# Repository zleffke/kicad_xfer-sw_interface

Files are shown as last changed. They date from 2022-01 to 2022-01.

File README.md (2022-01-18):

# kicad_xfer-sw_interface
Pulse Latching RF Transfer Switch Interface for VTGS SX-Band System.  
V1, Rev- Designed to Control a Single [Relcomm RTS-TS3AB-I](https://rfrelaystore.com/product/rts-ts3ab-i/) Transfer Switch.  

The VTGS SX-Band System uses four RTS-TS3AB-I transfer switches to set the RF receive path to an X310 USRP with Dual UBX-160s.
Two transfer switches select the receive band for the USRP Band A RX2 port and Band B RX2 port (S or X).
Two transfer switches select the receive polarization for the selected band (RHCP or LHCP).

## [Relcomm RTS-TS3AB-I](https://rfrelaystore.com/product/rts-ts3ab-i/) Transfer Switch Description
See linked product for full datasheet and feature list.  Features listed below are the pertinent features for the control circuit.
- Pulse Latching, short duration pulse on coil sets latched position.
- 28V Coil Voltage, common negative, pulse on positive side of Coil 1 or 2.
- Indicator feedback, 1P2T switch indicates position.

## V1, Rev- Circuit Design Features
This version / revision submitted to osh park for PCB fab on 20220118.
- TTL Level Control from MCU (+5V / +3V3)
- TTL Level Feedback for MCU (+5V / +3V3)
- Optically Isolated Control (ILD207T)
- LED Current Position Indicator (POS1 - RED, POS2 - BLUE)
- LED Set Position Indicator (pulsed, both green)
- Relay Coil Control via dual W6PQL based FET Switch circuits

## Credit where its due:
The transfer switches in this design are controlled by a [High Current DC Switch](https://www.w6pql.com/high_current_solid-state_dc_switch.htm) based on the W6PQL design.  The specific P-Channel MOSFET is modified for smaller form factor and lower current draw.  The DISABLE feature is not needed and not implemented.

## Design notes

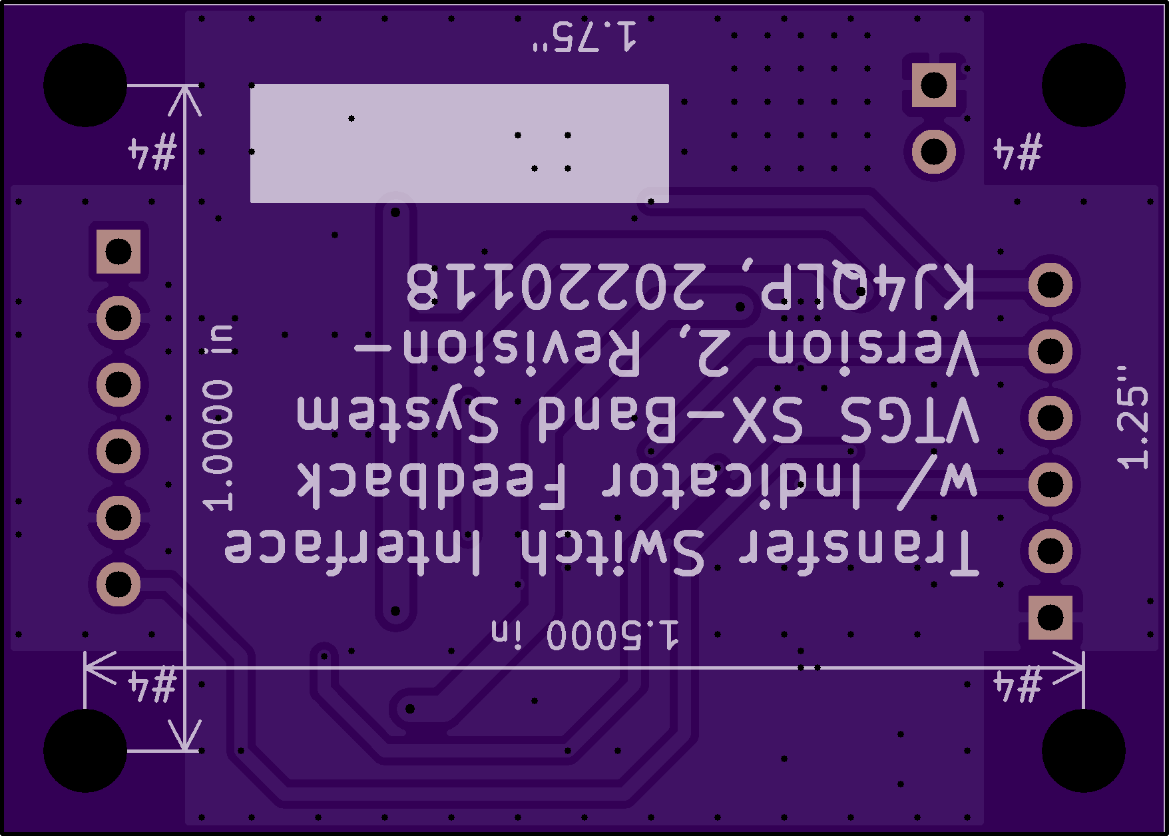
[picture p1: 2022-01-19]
v2/rev-/osh_park_bottom_view.png

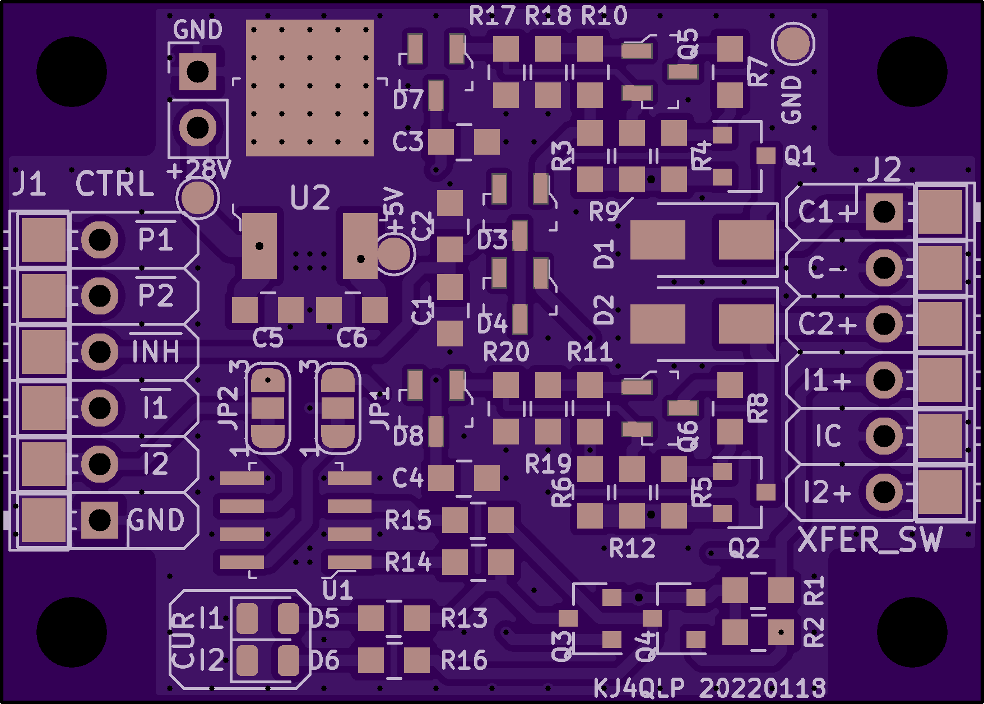
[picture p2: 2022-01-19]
v2/rev-/osh_park_top_view.png

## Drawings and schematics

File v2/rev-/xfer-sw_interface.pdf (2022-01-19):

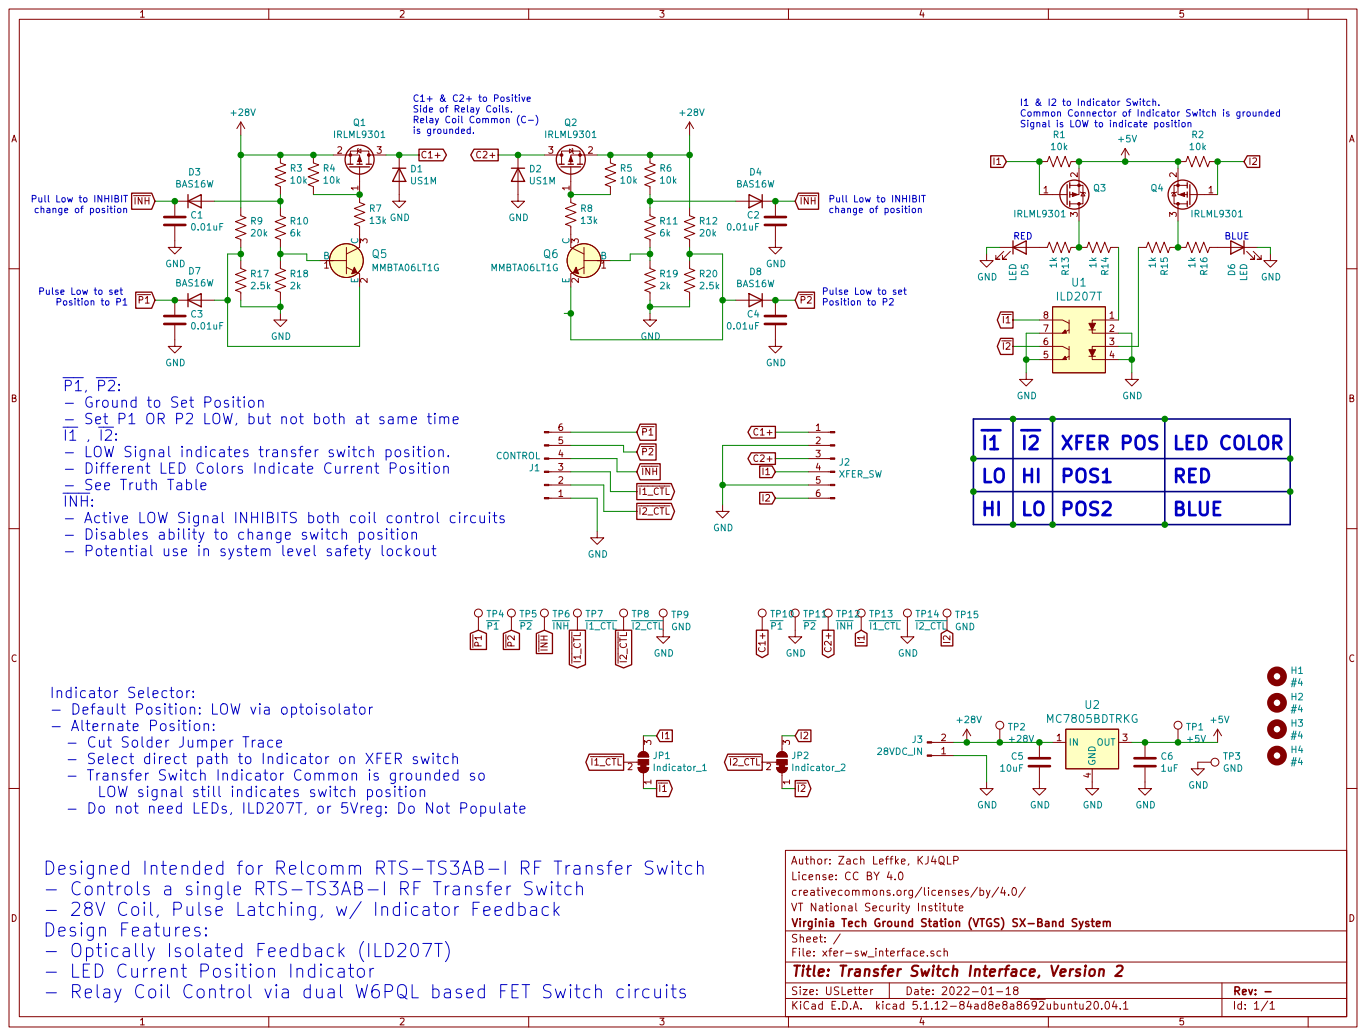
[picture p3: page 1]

Signal is LOW to indicate position C1+ & C2+ to Positive Side of Relay Coils.
10kTP9 GND

I1 & I2 to Indicator Switch. Common Connector of Indicator Switch is grounded

change of position Pulse Low to set Position to P2 Pull Low to INHIBIT
change of position Pulse Low to set Position to P1

Pull Low to INHIBIT
INH

- Ground to Set Position
- Set P1 OR P2 LOW, but not both at same time
- LOW Signal indicates transfer switch position.
- Different LED Colors Indicate Current Position
- See Truth Table
INH:
- Active LOW Signal INHIBITS both coil control circuits
- Disables ability to change switch position
- Potential use in system level safety lockout

Indicator Selector:
- Default Position: LOW via optoisolator
- Alternate Position:
- Cut Solder Jumper Trace
- Select direct path to Indicator on XFER switch
- Transfer Switch Indicator Common is grounded so
LOW signal still indicates switch position
- Do not need LEDs, ILD207T, or 5Vreg: Do Not Populate

creativecommons.org/licenses/by/4.0/ License: CC BY 4.0 Author: Zach Leffke, KJ4QLP

- Controls a single RTS-TS3AB-I RF Transfer Switch
- 28V Coil, Pulse Latching, w/ Indicator Feedback
Design Features:
- Optically Isolated Feedback (ILD207T)
- LED Current Position Indicator
- Relay Coil Control via dual W6PQL based FET Switch circuits

VT National Security Institute
File: xfer-sw_interface.sch Sheet: / Virginia Tech Ground Station (VTGS) SX-Band System

Id: 1/1 Title: Transfer Switch Interface, Version 2

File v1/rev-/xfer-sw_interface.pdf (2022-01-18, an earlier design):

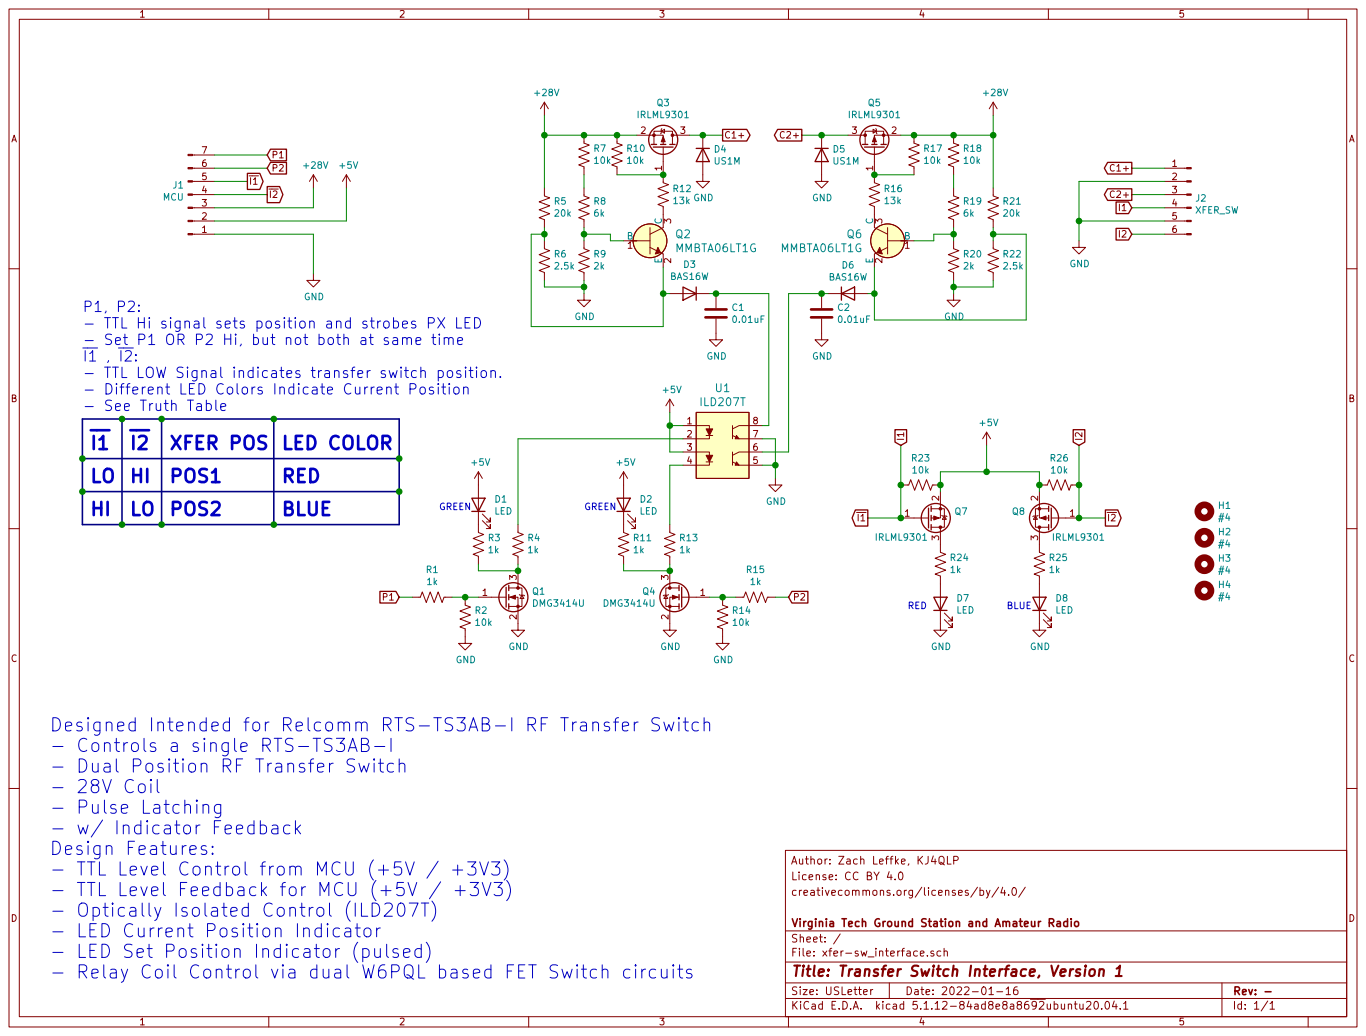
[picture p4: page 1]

- TTL Hi signal sets position and strobes PX LED
- Set P1 OR P2 Hi, but not both at same time
- TTL LOW Signal indicates transfer switch position.
- Different LED Colors Indicate Current Position
- See Truth Table

RED GREEN LED COLOR
RED
BLUE

Designed Intended for Relcomm RTS-TS3AB-I RF Transfer Switch
- Controls a single RTS-TS3AB-I
- Dual Position RF Transfer Switch
- 28V Coil
- Pulse Latching
- w/ Indicator Feedback
Design Features:
- TTL Level Control from MCU (+5V / +3V3)
- TTL Level Feedback for MCU (+5V / +3V3)
- Optically Isolated Control (ILD207T)
- LED Current Position Indicator
- LED Set Position Indicator (pulsed)
- Relay Coil Control via dual W6PQL based FET Switch circuits

creativecommons.org/licenses/by/4.0/ License: CC BY 4.0 Author: Zach Leffke, KJ4QLP

File: xfer-sw_interface.sch Sheet: / Virginia Tech Ground Station and Amateur Radio

Id: 1/1 Title: Transfer Switch Interface, Version 1

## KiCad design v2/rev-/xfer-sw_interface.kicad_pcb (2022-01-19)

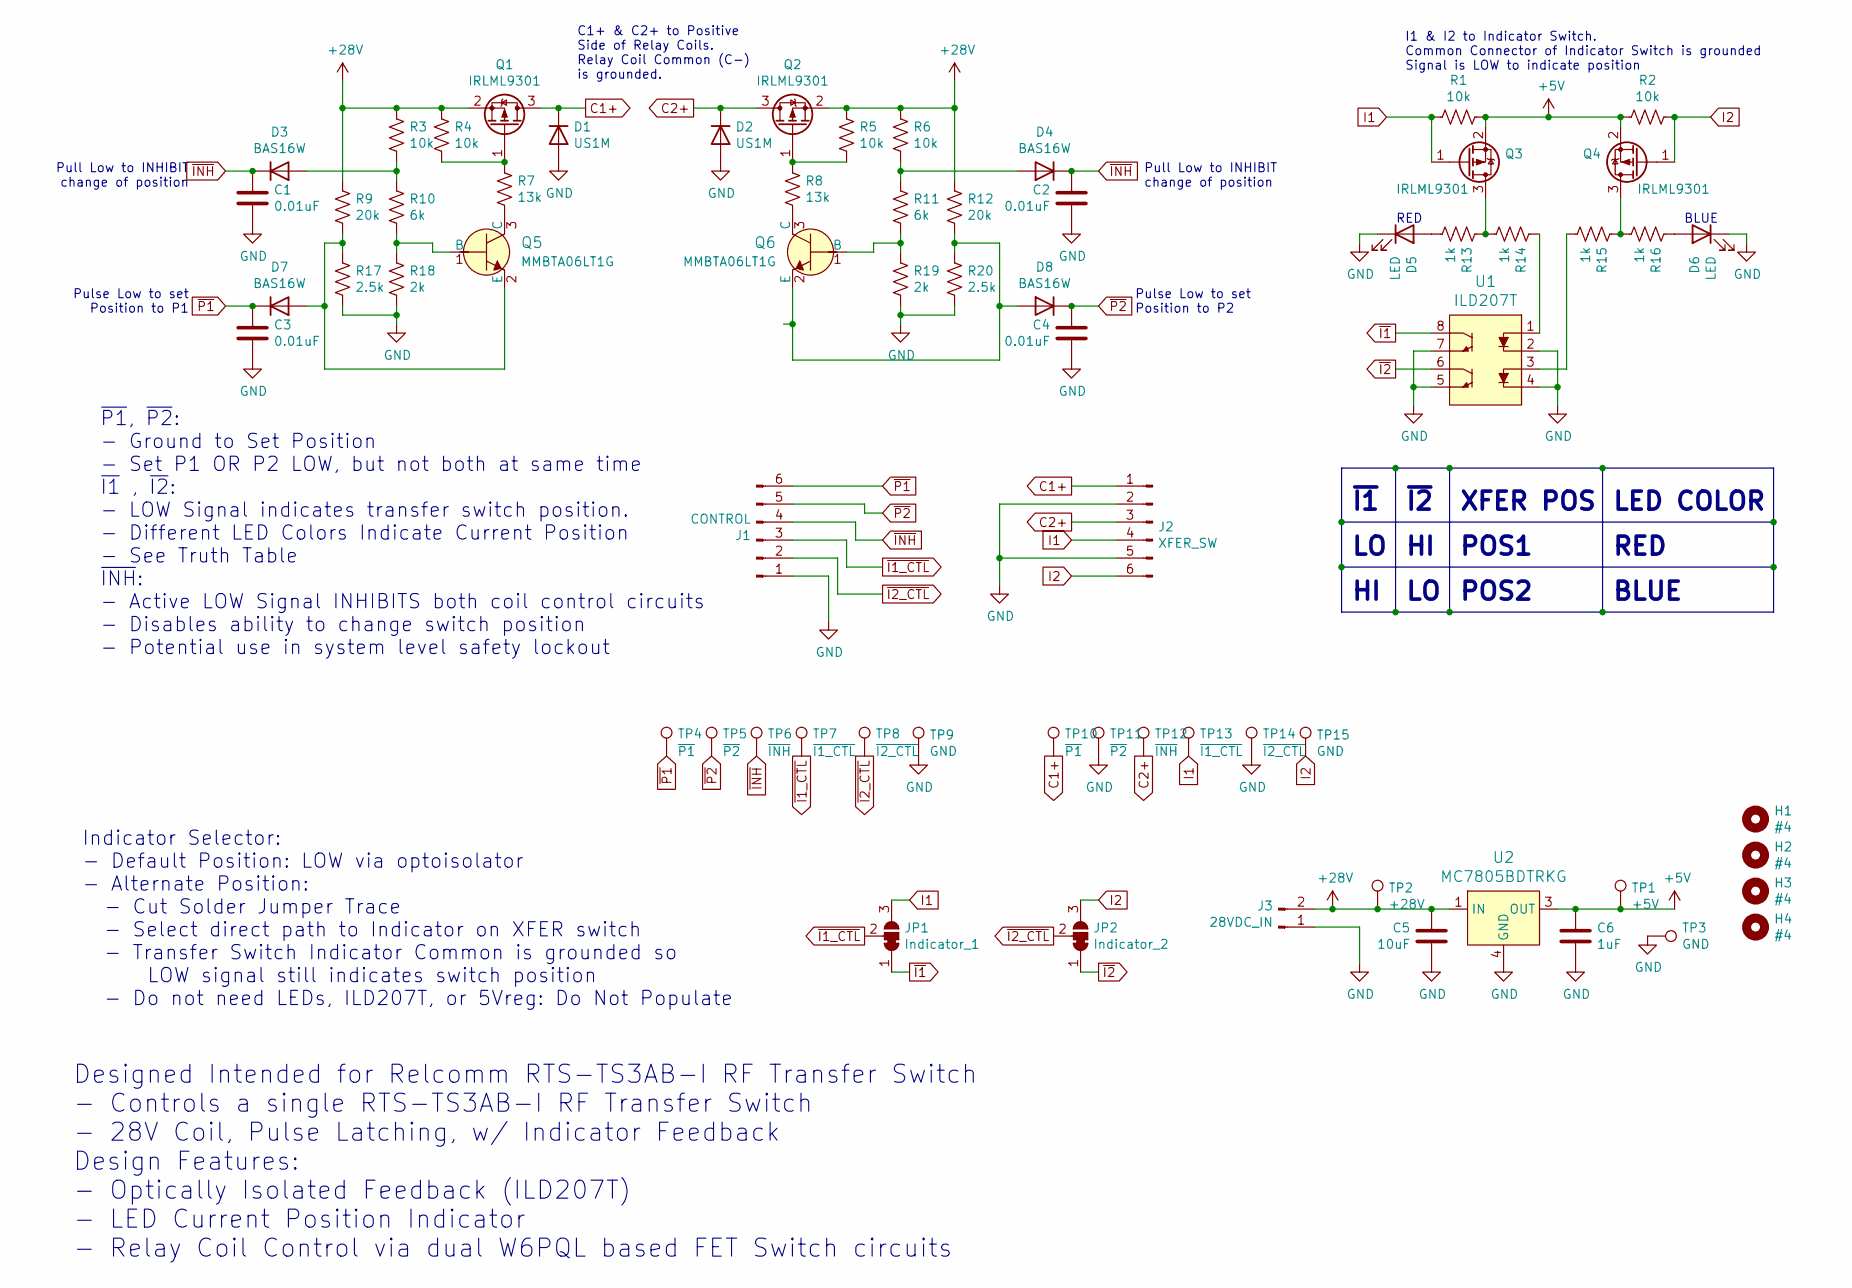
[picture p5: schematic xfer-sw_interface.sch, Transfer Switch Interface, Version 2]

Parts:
C1, C2, C3, C4: 0.01uF; 0805
C5: 10uF; 0805
C6: 1uF; 0805
D1, D2: US1M; D_SMA
D3, D4, D7, D8: BAS16W; SOT-23-3
D5, D6: LED; LED_0805_2012Metric
H1, H2, H3, H4: #4; MountingHole_3.2mm_M3
J1: CONTROL; PinHeader_1x06_P2.54mm_Horizontal
J2: XFER_SW; PinHeader_1x06_P2.54mm_Horizontal
J3: 28VDC_IN; PinHeader_1x02_P2.54mm_Vertical
JP1: Indicator_1; SolderJumper-3_P1.3mm_Bridged12_RoundedPad1.0x1.5mm_NumberL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
JP2: Indicator_2; SolderJumper-3_P1.3mm_Bridged12_RoundedPad1.0x1.5mm_NumberL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
Q1, Q2, Q3, Q4: IRLML9301; SOT-23
Q5, Q6: MMBTA06LT1G; SOT-23-3; MPN MMBTA06LT1G; Digi-Key_PN MMBTA06LT1GOSCT-ND
R1, R2, R3, R4, R5, R6: 10k; 0805
R7, R8: 13k; 0805
R9, R12: 20k; 0805
R10, R11: 6k; 0805
R13, R14, R15, R16: 1k; 0805
R17, R20: 2.5k; 0805
R18, R19: 2k; 0805
TP1: +5V; TestPoint_Pad_D1.5mm
TP2: +28V; TestPoint_Pad_D1.5mm
TP3: GND; TestPoint_Pad_D1.5mm
TP4, TP10: ~P1; TestPoint_Pad_2.0x2.0mm
TP5, TP11: ~P2; TestPoint_Pad_2.0x2.0mm
TP6, TP12: ~INH; TestPoint_Pad_2.0x2.0mm
TP7, TP13: ~I1_CTL; TestPoint_Pad_2.0x2.0mm
TP8, TP14: ~I2_CTL; TestPoint_Pad_2.0x2.0mm
TP9, TP15: GND; TestPoint_Pad_2.0x2.0mm
U1: ILD207T; SOIC-8_W3.9mm; MPN ILD207T; Digi-Key_PN 751-1310-1-ND
U2: MC7805BDTRKG; TO-252-3; MPN MC7805BDTRKG; Digi-Key_PN MC7805BDTRKGOSCT-ND

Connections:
+5V: C6.1, Q3.2 (S), Q4.2 (S), R1.1, R2.2, TP1.1, U2.3 (OUT)
+28V: C5.1, J3.2, Q1.2 (S), Q2.2 (S), R3.2, R4.2, R5.2, R6.2, R9.2, R12.2, TP2.1, U2.1 (IN)
C1+: D1.1 (K), J2.1, Q1.3 (D), TP10.1
C2+: D2.1 (K), J2.3, Q2.3 (D), TP12.1
GND: C1.2, C2.2, C3.2, C4.2, C5.2, C6.2, D1.2 (A), D2.2 (A), D5.1 (K), D6.1 (K), J1.1, J2.2, J2.5, J3.1, R17.1, R18.1, R19.1, R20.1, TP3.1, TP9.1, TP11.1, TP14.1, U1.2, U1.4, U1.5, U1.7, U2.4 (GND)
I1: J2.4, JP1.3 (B), Q3.1 (G), R1.2, TP13.1
I2: J2.6, JP2.3 (B), Q4.1 (G), R2.1, TP15.1
unnamed: D3.1 (A), R3.1, R10.2
unnamed: D4.1 (A), R6.1, R11.2
unnamed: D5.2 (A), R13.1
unnamed: D6.2 (A), R16.2
unnamed: D7.1 (A), Q5.2 (E), R9.1, R17.2
unnamed: D8.1 (A), Q6.2 (E), R12.1, R20.2
unnamed: Q1.1 (G), R4.1, R7.1
unnamed: Q2.1 (G), R5.1, R8.1
unnamed: Q3.3 (D), R13.2, R14.1
unnamed: Q4.3 (D), R15.2, R16.1
unnamed: Q5.1 (B), R10.1, R18.2
unnamed: Q5.3 (C), R7.2
unnamed: Q6.1 (B), R11.1, R19.2
unnamed: Q6.3 (C), R8.2
unnamed: R14.2, U1.1
unnamed: R15.1, U1.3
~I1: JP1.1 (A), U1.8
~I1_CTL: J1.3, JP1.2 (C), TP7.1
~I2: JP2.1 (A), U1.6
~I2_CTL: J1.2, JP2.2 (C), TP8.1
~INH: C1.1, C2.1, D3.3 (K), D4.3 (K), J1.4, TP6.1
~P1: C3.1, D7.3 (K), J1.6, TP4.1
~P2: C4.1, D8.3 (K), J1.5, TP5.1

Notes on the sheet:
~P1~, ~P2~: - Ground to Set Position - Set P1 OR P2 LOW, but not both at same time ~I1~ , ~I2~: - LOW Signal indicates transfer switch position. - Different LED Colors Indicate Current Position - See Truth Table ~INH~: - Active LOW Signal INHIBITS both coil control circuits - Disables ability to ch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
~I1
~I2
XFER POS
POS2
POS1
RED
BLUE
LED COLOR
Designed Intended for Relcomm RTS-TS3AB-I RF Transfer Switch - Controls a single RTS-TS3AB-I RF Transfer Switch - 28V Coil, Pulse Latching, w/ Indicator Feedback Design Features: - Optically Isolated Feedback (ILD207T) - LED Current Position Indicator - Relay Coil Control via dual W6PQL based FET S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
Indicator Selector: - Default Position: LOW via optoisolator - Alternate Position: - Cut Solder Jumper Trace - Select direct path to Indicator on XFER switch - Transfer Switch Indicator Common is grounded so LOW signal still indicates switch position - Do not need LEDs, ILD207T, or 5Vreg: Do Not Po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
C1+ & C2+ to Positive Side of Relay Coils. Relay Coil Common (C-) is grounded.
I1 & I2 to Indicator Switch. Common Connector of Indicator Switch is grounded Signal is LOW to indicate position
Pulse Low to set Position to P1
Pull Low to INHIBIT change of position
Pulse Low to set Position to P2

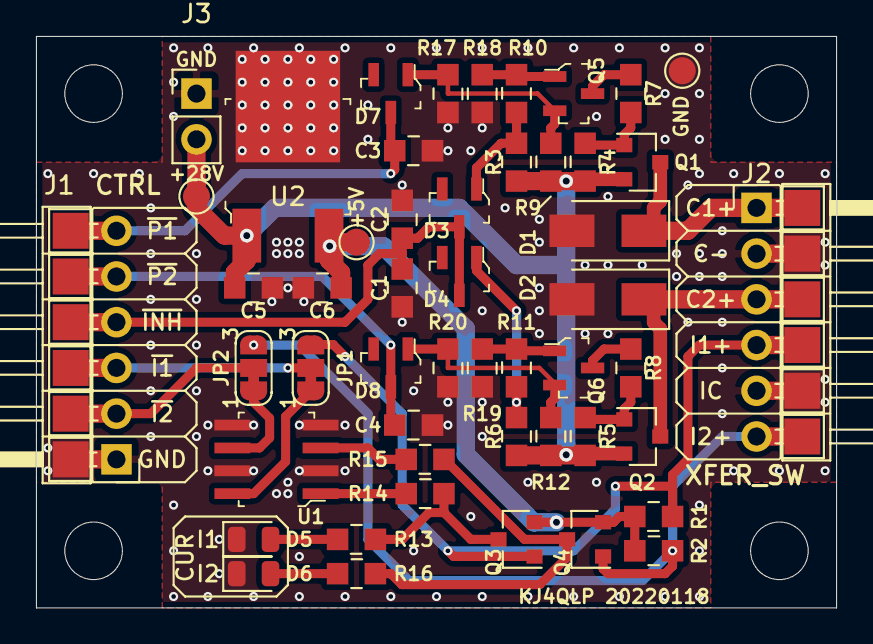
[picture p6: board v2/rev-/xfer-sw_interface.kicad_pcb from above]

Board: 2 copper layers, 44.4 x 31.8 mm, 66 parts (0 on the bottom side), 30 nets.

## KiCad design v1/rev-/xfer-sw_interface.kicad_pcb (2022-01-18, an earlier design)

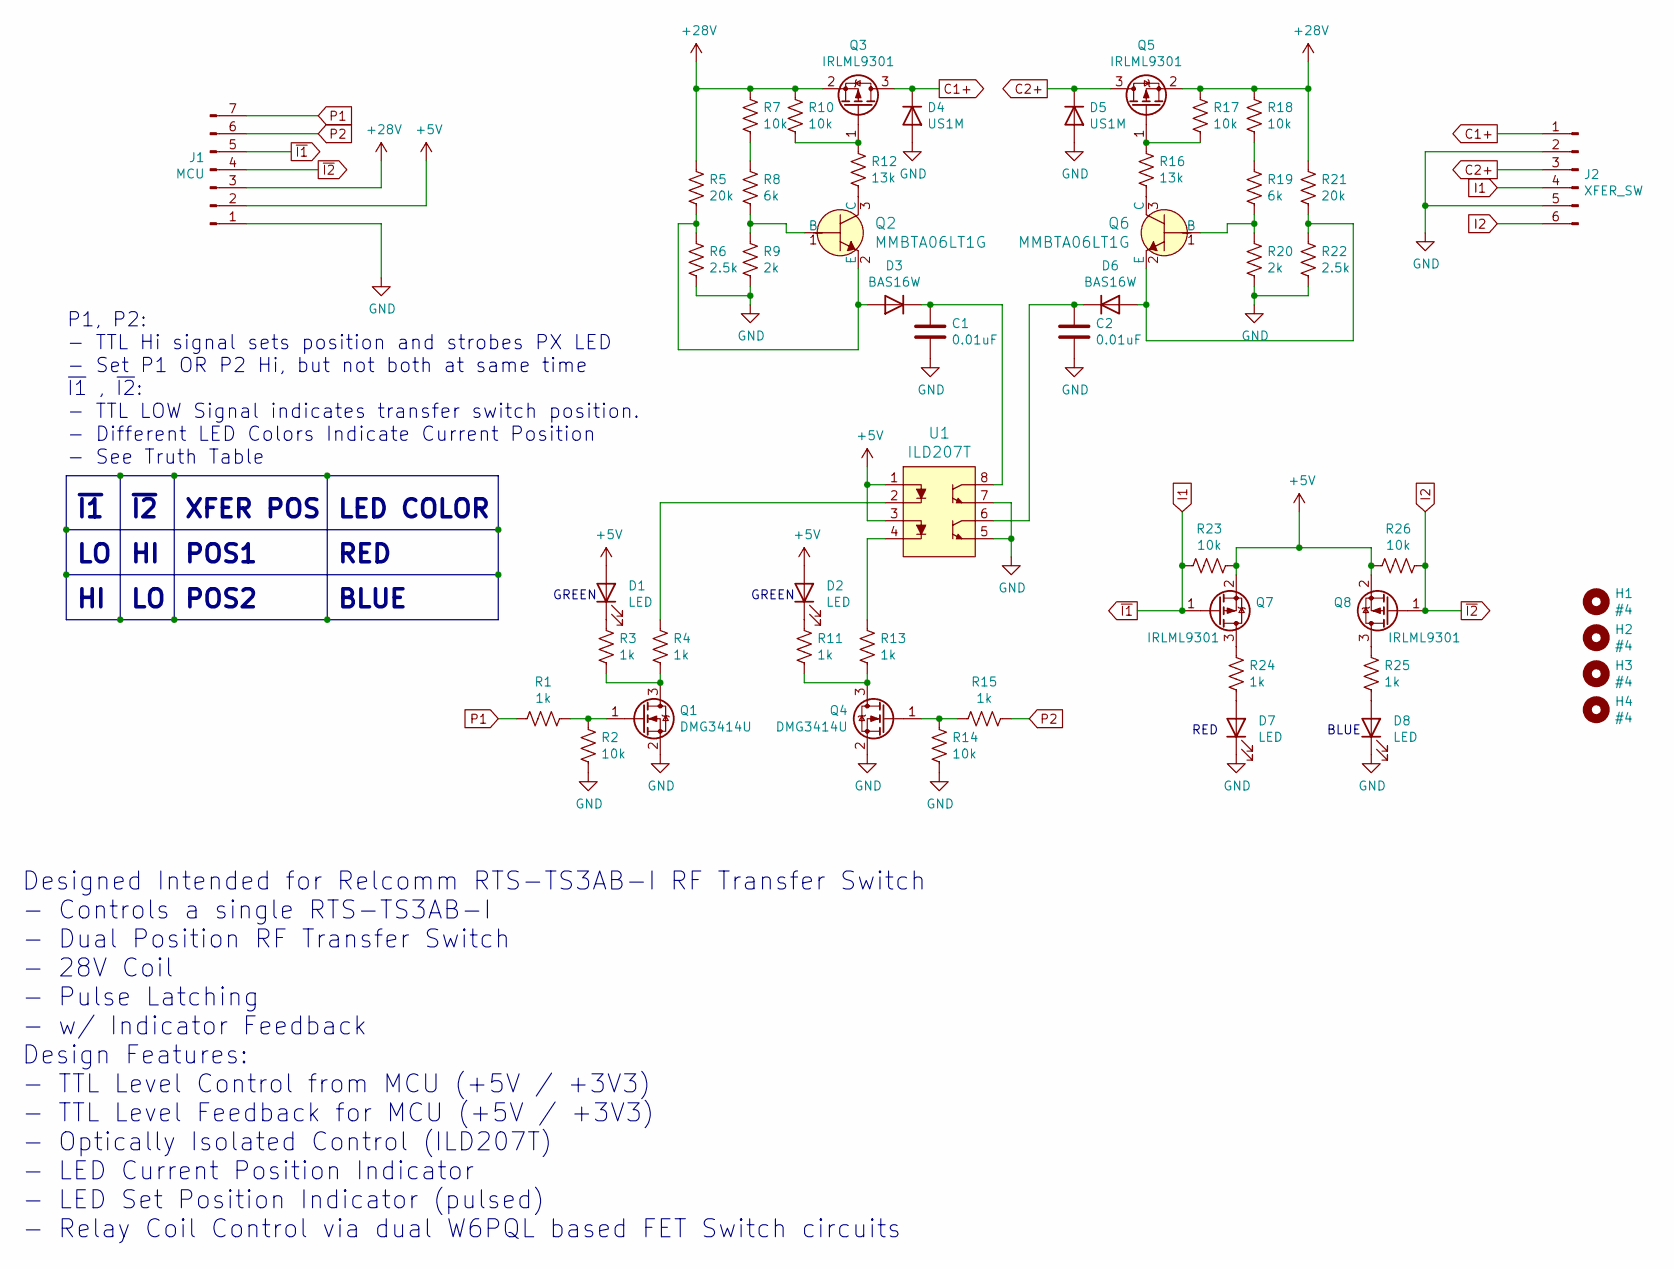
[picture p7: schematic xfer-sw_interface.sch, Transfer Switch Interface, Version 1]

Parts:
C1, C2: 0.01uF; 0805
D1, D2, D7, D8: LED; LED_0805_2012Metric
D3, D6: BAS16W; SOT-23-3
D4, D5: US1M; D_SMA
H1, H2, H3, H4: #4; MountingHole_3.2mm_M3
J1: MCU; PinHeader_1x07_P2.54mm_Horizontal
J2: XFER_SW; PinHeader_1x06_P2.54mm_Horizontal
Q1, Q4: DMG3414U; SOT-23
Q2, Q6: MMBTA06LT1G; SOT-23-3; MPN MMBTA06LT1G; Digi-Key_PN MMBTA06LT1GOSCT-ND
Q3, Q5, Q7, Q8: IRLML9301; SOT-23
R1, R3, R4, R11, R13, R15, R24, R25: 1k; 0805
R2, R7, R10, R14, R17, R18, R23, R26: 10k; 0805
R5, R21: 20k; 0805
R6, R22: 2.5k; 0805
R8, R19: 6k; 0805
R9, R20: 2k; 0805
R12, R16: 13k; 0805
U1: ILD207T; SOIC-8_W3.9mm; MPN ILD207T; Digi-Key_PN 751-1310-1-ND

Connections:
+5V: D1.2 (A), D2.2 (A), J1.2, Q7.2 (S), Q8.2 (S), R23.1, R26.2, U1.1, U1.3
+28V: J1.3, Q3.2 (S), Q5.2 (S), R5.2, R7.2, R10.2, R17.2, R18.2, R21.2
C1+: D4.1 (K), J2.1, Q3.3 (D)
C2+: D5.1 (K), J2.3, Q5.3 (D)
GND: C1.2, C2.2, D4.2 (A), D5.2 (A), D7.1 (K), D8.1 (K), J1.1, J2.2, J2.5, Q1.2 (S), Q4.2 (S), R2.1, R6.1, R9.1, R14.1, R20.1, R22.1, U1.5, U1.7
I1: J1.5, J2.4, Q7.1 (G), R23.2
I2: J1.4, J2.6, Q8.1 (G), R26.1
unnamed: C1.1, D3.3 (K), U1.8
unnamed: C2.1, D6.3 (K), U1.6
unnamed: D1.1 (K), R3.2
unnamed: D2.1 (K), R11.2
unnamed: D3.1 (A), Q2.2 (E), R5.1, R6.2
unnamed: D6.1 (A), Q6.2 (E), R21.1, R22.2
unnamed: D7.2 (A), R24.1
unnamed: D8.2 (A), R25.1
unnamed: Q1.1 (G), R1.2, R2.2
unnamed: Q1.3 (D), R3.1, R4.1
unnamed: Q2.1 (B), R8.1, R9.2
unnamed: Q2.3 (C), R12.2
unnamed: Q3.1 (G), R10.1, R12.1
unnamed: Q4.1 (G), R14.2, R15.1
unnamed: Q4.3 (D), R11.1, R13.1
unnamed: Q5.1 (G), R16.1, R17.1
unnamed: Q6.1 (B), R19.1, R20.2
unnamed: Q6.3 (C), R16.2
unnamed: Q7.3 (D), R24.2
unnamed: Q8.3 (D), R25.2
unnamed: R4.2, U1.2
unnamed: R7.1, R8.2
unnamed: R13.2, U1.4
unnamed: R18.1, R19.2
P1: J1.7, R1.1
P2: J1.6, R15.2

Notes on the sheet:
Designed Intended for Relcomm RTS-TS3AB-I RF Transfer Switch - Controls a single RTS-TS3AB-I - Dual Position RF Transfer Switch - 28V Coil - Pulse Latching - w/ Indicator Feedback Design Features: - TTL Level Control from MCU (+5V / +3V3) - TTL Level Feedback for MCU (+5V / +3V3) - Optically Isolat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
P1, P2: - TTL Hi signal sets position and strobes PX LED - Set P1 OR P2 Hi, but not both at same time ~I1~ , ~I2~: - TTL LOW Signal indicates transfer switch position. - Different LED Colors Indicate Current Position - See Truth Table
~I1
~I2
XFER POS
POS2
POS1
RED
GREEN
BLUE
LED COLOR

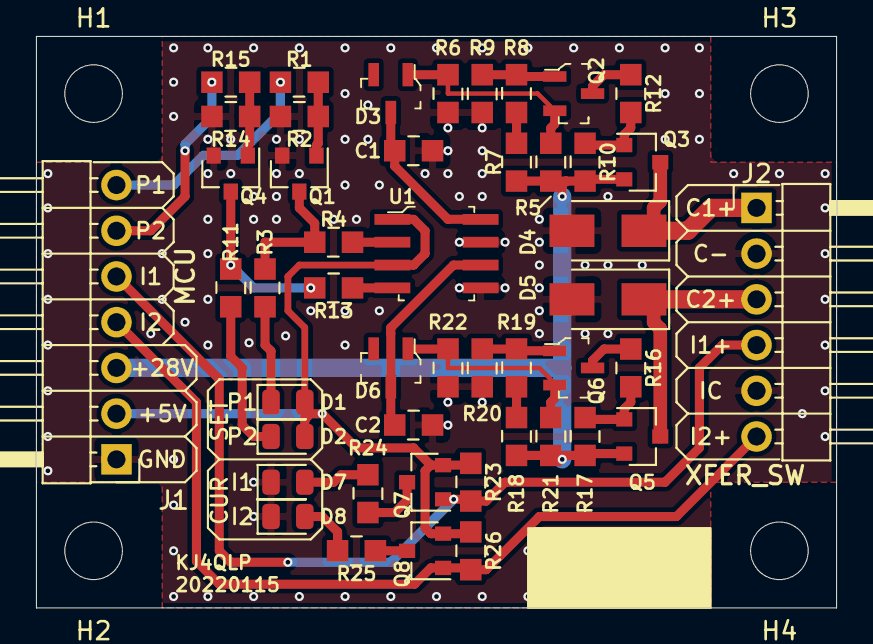
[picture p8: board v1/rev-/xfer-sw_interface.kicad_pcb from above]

Board: 2 copper layers, 44.4 x 31.8 mm, 51 parts (0 on the bottom side), 33 nets.

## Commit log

2022-01-18 completed v1, rev-. this commit submitted to osh park 20220118.
    [xfer-sw_interface.kicad_pcb, xfer-sw_interface.sch]
2022-01-18 initial v2 commit. non-ttl ctrl, opto isolated feedback.
    [xfer-sw_interface.kicad_pcb, xfer-sw_interface.sch]
2022-01-19 version 2 of xfer switch interface design. This commit sent to osh park 20220119
    [xfer-sw_interface.kicad_pcb, xfer-sw_interface.sch]
